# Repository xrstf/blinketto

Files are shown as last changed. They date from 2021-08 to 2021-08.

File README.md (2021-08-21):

# Blinketto - Controlling my PixelPals remotely

This repository contains the source code, schematics and everything else for my
LED controller.

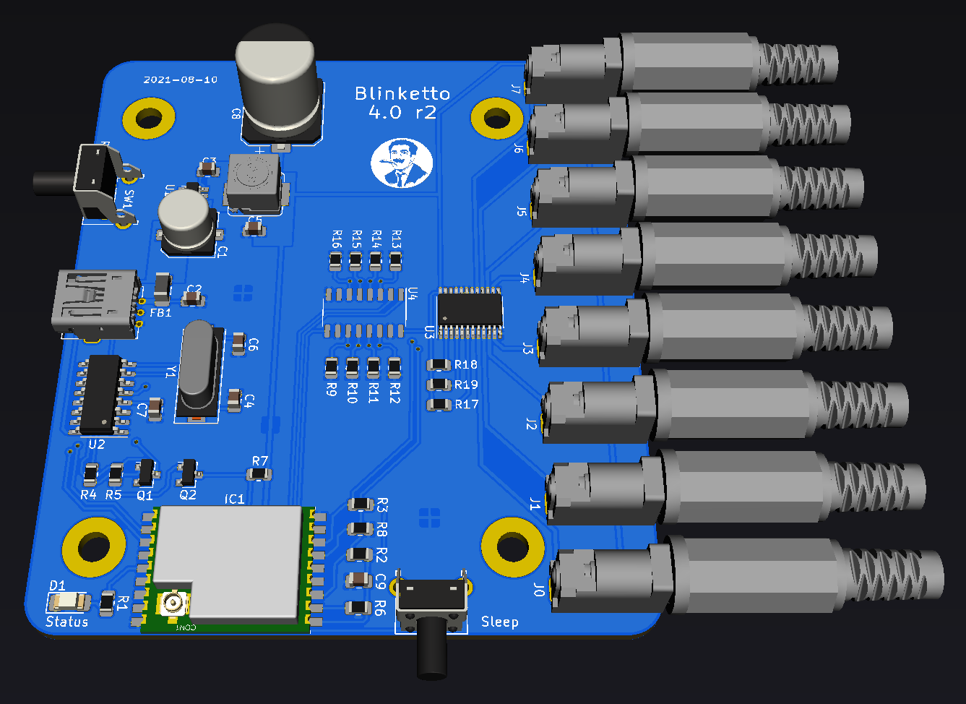
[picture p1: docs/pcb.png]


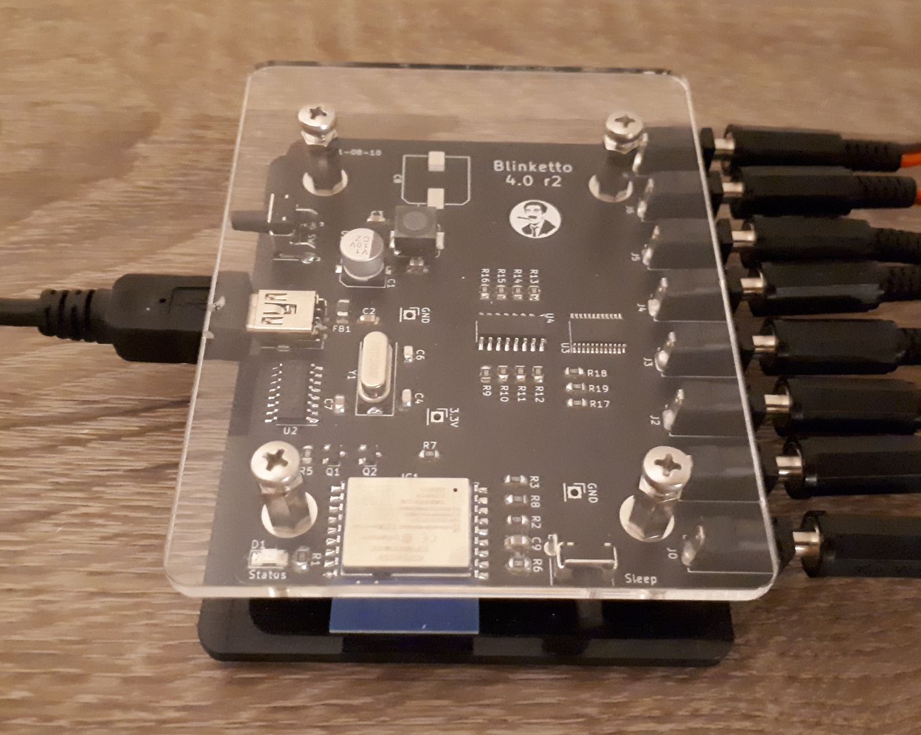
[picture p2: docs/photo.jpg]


---

Blinketto was named after the Plinketto device in one of my favorite web series,
["Best of the Worst"](https://www.youtube.com/user/RedLetterMedia).

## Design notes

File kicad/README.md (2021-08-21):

# KiCad Designs

These designs require that https://github.com/xrstf/kicad-library is set up in your
local KiCad 5 installation.

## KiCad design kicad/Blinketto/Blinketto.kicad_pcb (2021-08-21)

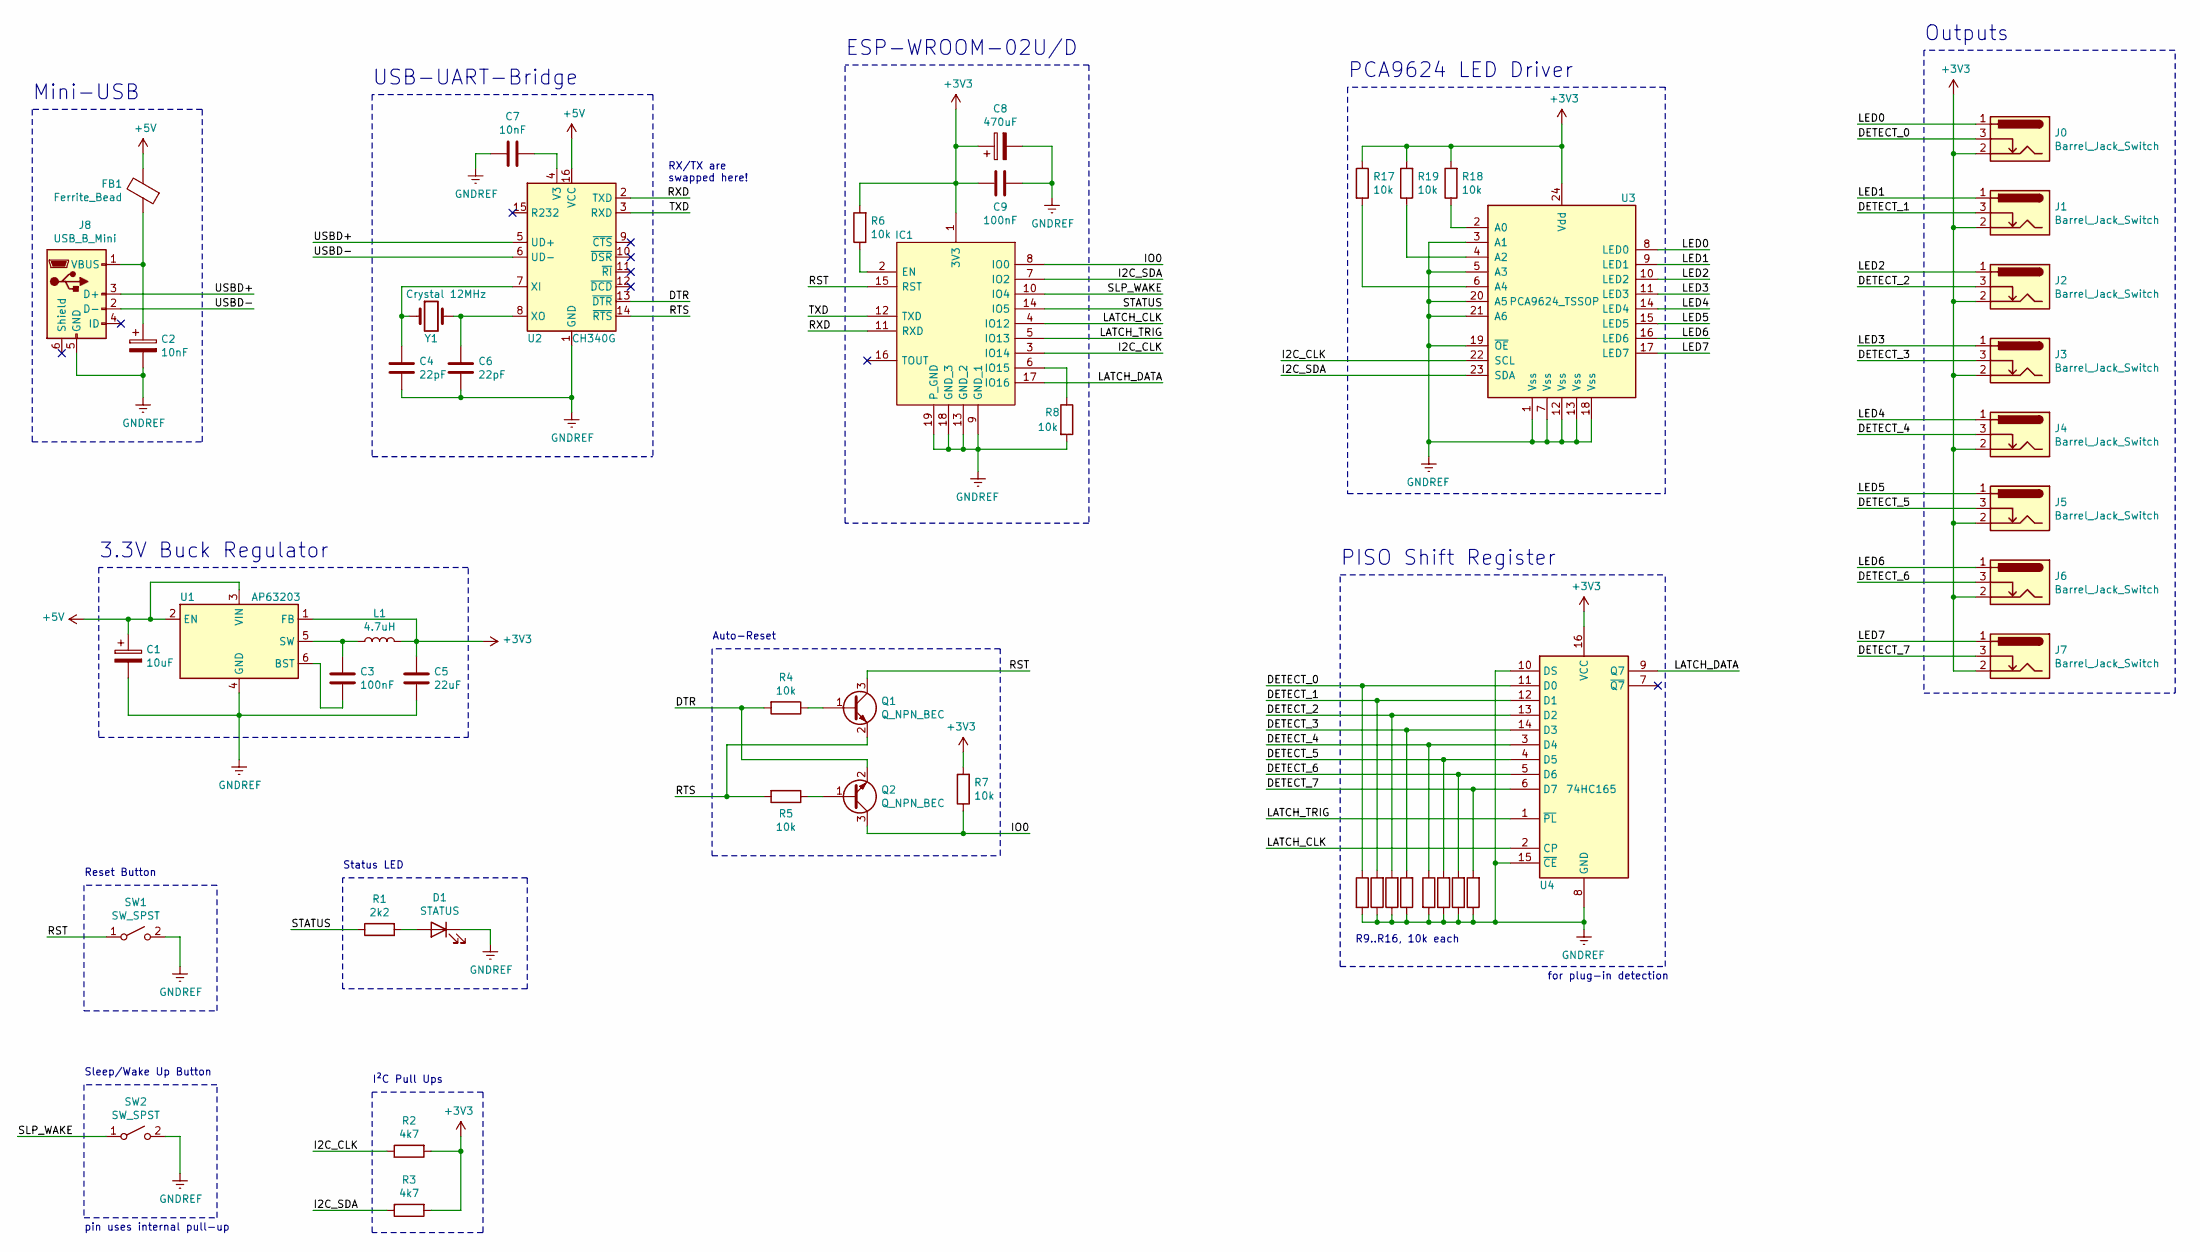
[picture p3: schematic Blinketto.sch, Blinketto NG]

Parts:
C1: 10uF; C_Elec_6.3x5.8
C2, C7: 10nF; C_0805_2012Metric
C3, C9: 100nF; C_0805_2012Metric
C4, C6: 22pF; C_0805_2012Metric
C5: 22uF; C_0805_2012Metric
C8: 470uF; CP_Elec_10x12.5
D1: STATUS; LED_1206_3216Metric_Pad1.42x1.75mm_HandSolder
FB1: Ferrite_Bead; L_1206_3216Metric_Pad1.42x1.75mm_HandSolder
IC1: ESP-WROOM-02U__4MB_; ESP-WROOM-02U
J0, J1, J2, J3, J4, J5, J6, J7: Barrel_Jack_Switch; Lumberg_1613-26_BarrelJack
J8: USB_B_Mini; USB_BWM_MIniUSB_THT_reichelt
L1: 4.7uH; Bourns_SRR0604_7.3x6.6mm
Q1, Q2: Q_NPN_BEC; SOT-23
R1: 2k2; R_0805_2012Metric
R2, R3: 4k7; R_0805_2012Metric
R4, R5, R6, R7, R8, R9, R10, R11, R12, R13, R14, R15, R16, R17, R18, R19: 10k; R_0805_2012Metric
SW1, SW2: SW_SPST; SW_Tactile_SPST_Angled_PTS645Vx83-2LFS
U1: AP63203; TSOT-23-6
U2: CH340G; SOIC-16_3.9x9.9mm_P1.27mm
U3: PCA9624_TSSOP; TSSOP-24_4.4x7.8mm_P0.65mm
U4: 74HC165; SO-16_3.9x9.9mm_P1.27mm
Y1: Crystal 12MHz; Crystal_SMD_HC49-SD

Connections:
+3V3: C5.2, C8.1, C9.1, IC1.1 (3V3), J0.2, J1.2, J2.2, J3.2, J4.2, J5.2, J6.2, J7.2, L1.2, R2.2, R3.2, R6.2, R7.2, R17.1, R18.2, R19.2, U1.1 (FB), U3.24 (Vdd), U4.16 (VCC)
+5V: C1.1, FB1.2, U1.2 (EN), U1.3 (VIN), U2.16 (VCC)
/DETECT_0: J0.3, R9.1, U4.11 (D0)
/DETECT_1: J1.3, R10.2, U4.12 (D1)
/DETECT_2: J2.3, R11.2, U4.13 (D2)
/DETECT_3: J3.3, R12.2, U4.14 (D3)
/DETECT_4: J4.3, R13.1, U4.3 (D4)
/DETECT_5: J5.3, R14.2, U4.4 (D5)
/DETECT_6: J6.3, R15.2, U4.5 (D6)
/DETECT_7: J7.3, R16.2, U4.6 (D7)
/DTR: Q2.2 (E), R4.2, U2.13 (~DTR)
/I2C_CLK: IC1.3 (IO14), R2.1, U3.22 (SCL)
/I2C_SDA: IC1.7 (IO2), R3.1, U3.23 (SDA)
/IO0: IC1.8 (IO0), Q2.3 (C), R7.1
/LATCH_CLK: IC1.4 (IO12), U4.2 (CP)
/LATCH_DATA: IC1.17 (IO16), U4.9 (Q7)
/LATCH_TRIG: IC1.5 (IO13), U4.1 (~PL)
/LED0: J0.1, U3.8 (LED0)
/LED1: J1.1, U3.9 (LED1)
/LED2: J2.1, U3.10 (LED2)
/LED3: J3.1, U3.11 (LED3)
/LED4: J4.1, U3.14 (LED4)
/LED5: J5.1, U3.15 (LED5)
/LED6: J6.1, U3.16 (LED6)
/LED7: J7.1, U3.17 (LED7)
/RST: IC1.15 (RST), Q1.3 (C), SW1.1 (A)
/RTS: Q1.2 (E), R5.2, U2.14 (~RTS)
/RXD: IC1.11 (RXD), U2.2 (TXD)
/SLP_WAKE: IC1.10 (IO4), SW2.1 (A)
/STATUS: IC1.14 (IO5), R1.1
/TXD: IC1.12 (TXD), U2.3 (RXD)
/USBD+: J8.3 (D+), U2.5 (UD+)
/USBD-: J8.2 (D-), U2.6 (UD-)
GNDREF: C1.2, C2.2, C4.1, C5.1, C6.1, C7.1, C8.2, C9.2, D1.1 (K), IC1.9 (GND_1), IC1.13 (GND_2), IC1.18 (GND_3), IC1.19 (P_GND), J8.5 (GND), R8.2, R9.2, R10.1, R11.1, R12.1, R13.2, R14.1, R15.1, R16.1, SW1.2 (B), SW2.2 (B), U1.4 (GND), U2.1 (GND), U3.1 (Vss), U3.3 (A1), U3.5 (A3), U3.7 (Vss), U3.12 (Vss), U3.13 (Vss), U3.18 (Vss), U3.19 (~OE), U3.20 (A5), U3.21 (A6), U4.8 (GND), U4.10 (DS), U4.15 (~CE)
unnamed: C2.1, FB1.1, J8.1 (VBUS)
unnamed: C3.1, U1.6 (BST)
unnamed: C3.2, L1.1, U1.5 (SW)
unnamed: C4.2, U2.7 (XI), Y1.1
unnamed: C6.2, U2.8 (XO), Y1.2
unnamed: C7.2, U2.4 (V3)
unnamed: D1.2 (A), R1.2
unnamed: IC1.2 (EN), R6.1
unnamed: IC1.6 (IO15), R8.1
unnamed: Q1.1 (B), R4.1
unnamed: Q2.1 (B), R5.1
unnamed: R17.2, U3.6 (A4)
unnamed: R18.1, U3.2 (A0)
unnamed: R19.1, U3.4 (A2)

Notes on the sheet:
Mini-USB
Status LED
Auto-Reset
ESP-WROOM-02U/D
Reset Button
3.3V Buck Regulator
PCA9624 LED Driver
PISO Shift Register
for plug-in detection
Outputs
Sleep/Wake Up Button
I²C Pull Ups
RX/TX are swapped here!
USB-UART-Bridge
pin uses internal pull-up
R9..R16, 10k each

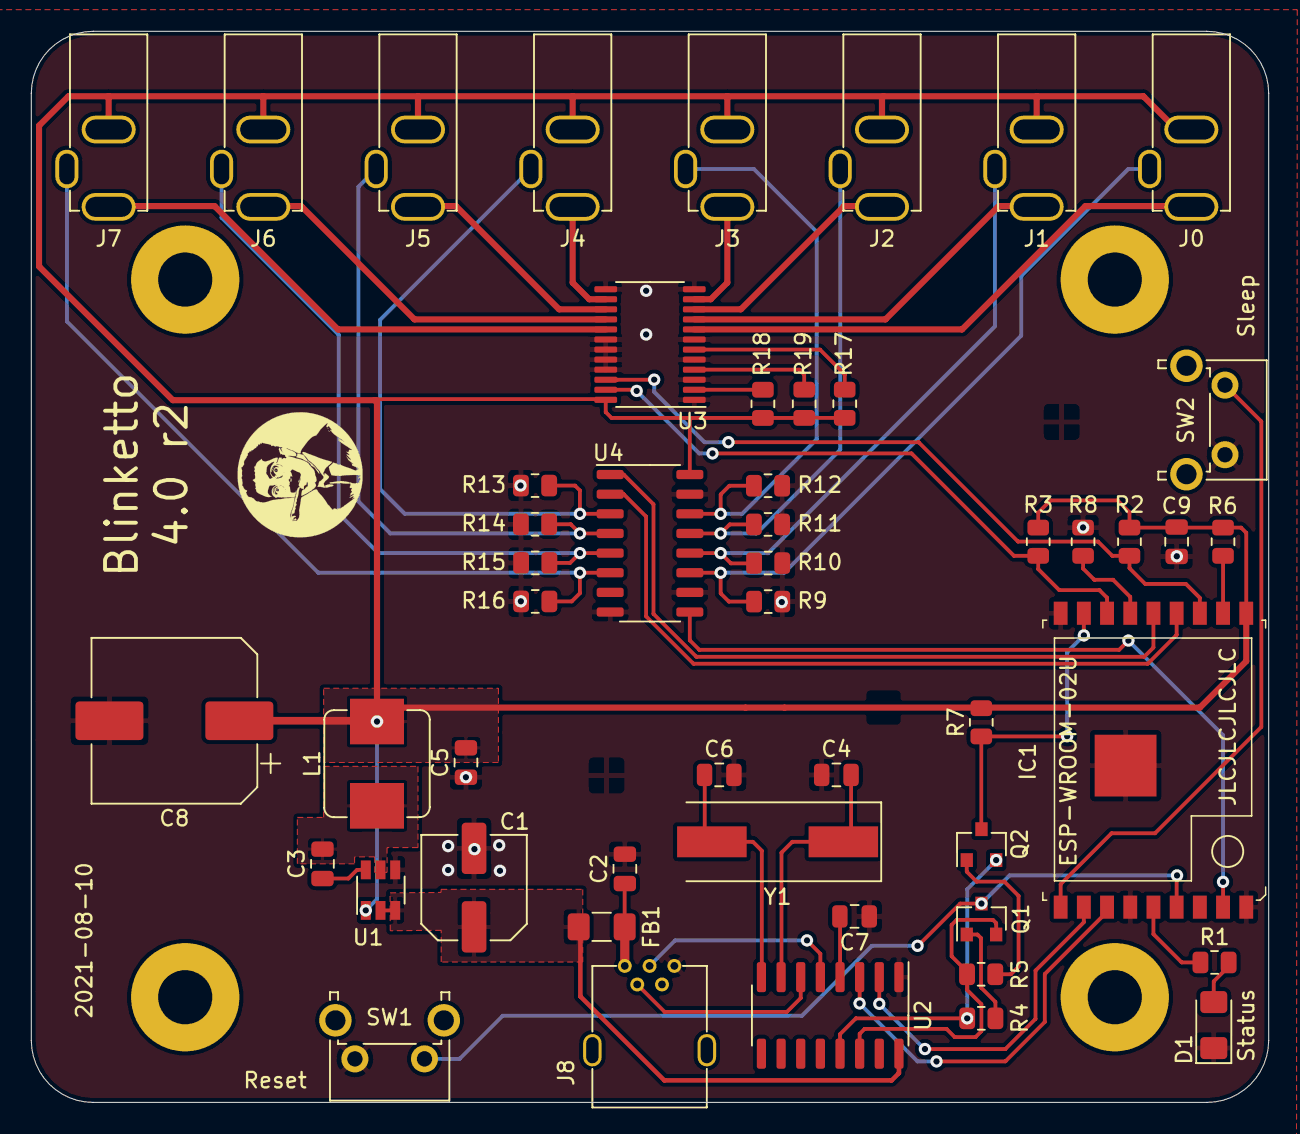
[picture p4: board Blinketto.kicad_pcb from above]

Board: 2 copper layers, 80.0 x 69.2 mm, 50 parts (0 on the bottom side), 48 nets.

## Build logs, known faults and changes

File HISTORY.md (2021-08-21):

# Blinketto History

Come on, sit down and let's have a laugh at the things I fucked up and what I learned over time. :)

## Blinketto 1.x

Was still based on a PIC microcontroller and I never designed a board for this. Getting
starting with PICs was more effort than expected, so I reverted back to Atmel and Arduino IDE
for 2.x

## Blinketto 2.0

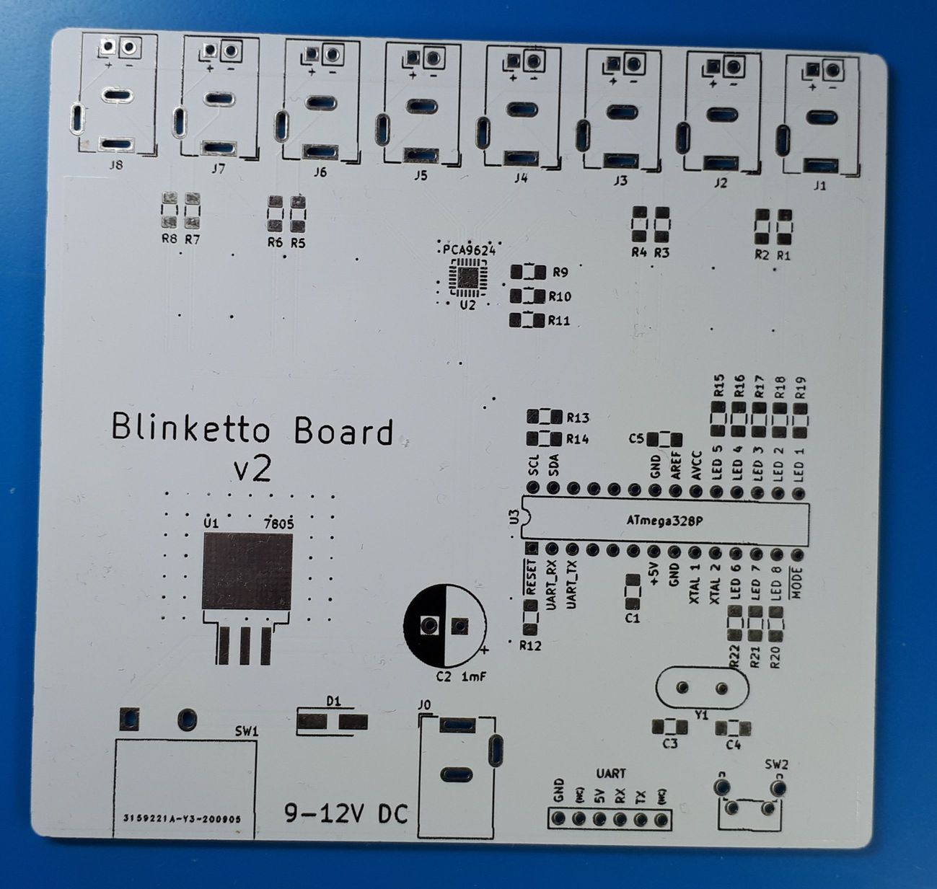
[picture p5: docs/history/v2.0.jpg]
Blinketto 2.0


The first version.

Things that sucked:

* The footprint for the LED driver was too hard for me to solder by hand. I ruined 2 boards while
  attempting to solder. At that point I did not own a hot air station or a heat plate.
* Debugging the I²C bus between the ATmega and the LED driver was impossible.
* No status LEDs, so I often wasn't even sure if the microcontroller was doing anything.
* White PCBs are amazingly ugly.

## Blinketto 2.1

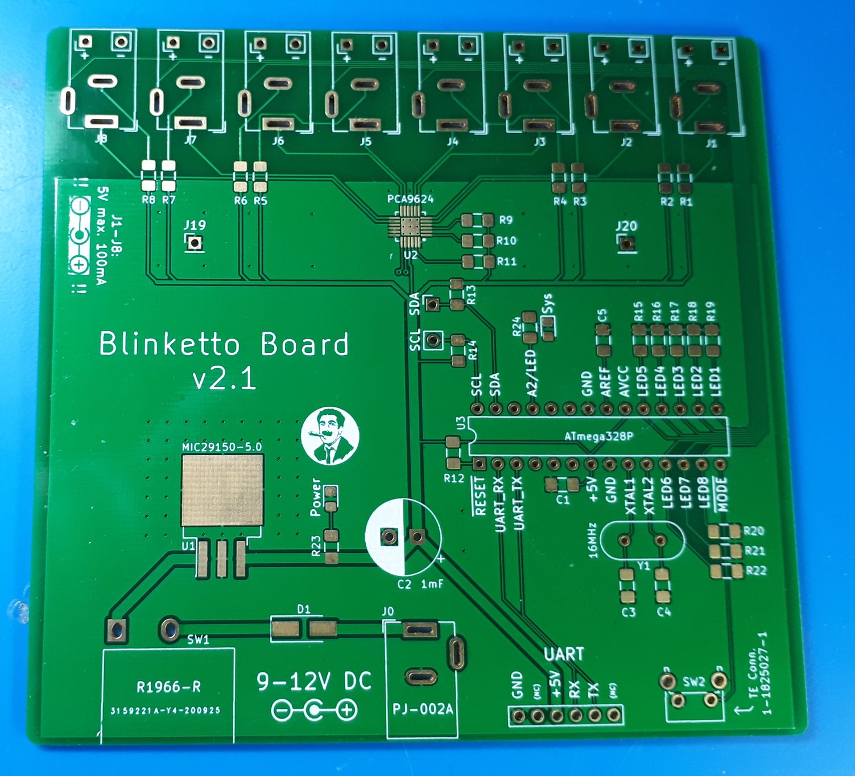
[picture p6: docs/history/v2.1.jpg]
Blinketto 2.1


Now with fancy status LEDs, pin headers to allow debugging the I²C bus and a modified footprint
for the LED driver, making soldering easier. J19 and J20 provide easier access to GND. I also put
better silkscreen on it, describing the pinouts and parts in more detail.

## Blinketto 2.2

The LED driver footprint was still too hard to solder, but I learned that a TSSOP package was
also available, so I switched over. Unfortunately I did not expect that the pinout would change
(i.e. pin 6 on the TSSOP is different from pin 6 on the LGA package), so my board was fubar.
I caught this before ordering and fixed it in v2.3.

## Blinketto 2.3

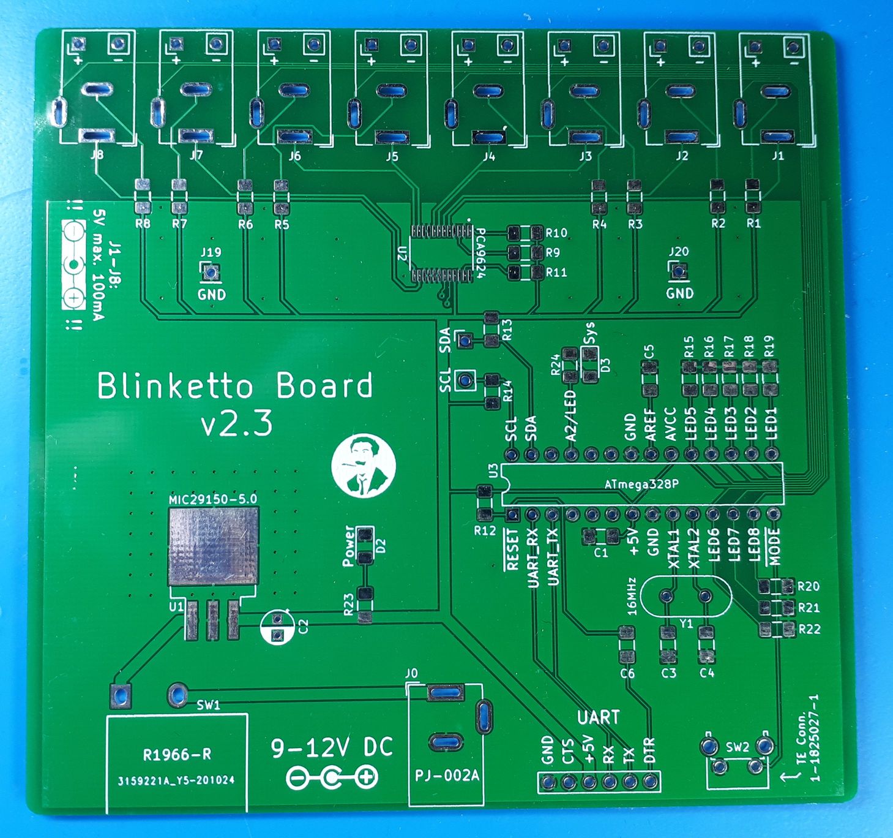
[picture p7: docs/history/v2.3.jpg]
Blinketto 2.3


This is the first time I realized that the 2 pins I didn't connect before (CTS and DTR)
are actually useful and required to make the UART stuff and uploading via Arduino IDE possible.
So I begun connecting them properly.

## Blinketto 3.0

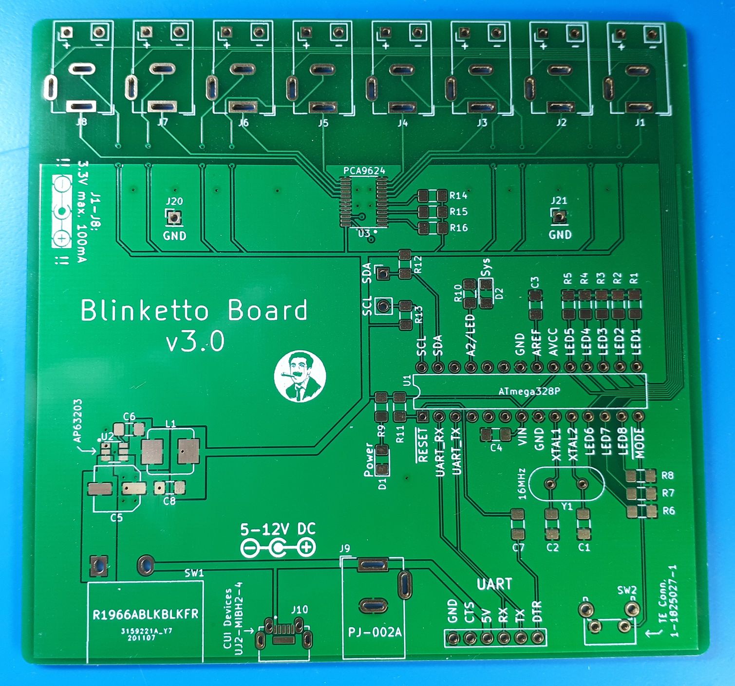
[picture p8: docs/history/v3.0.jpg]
Blinketto 3.0


The linear regulator was easy to use, but ran very hot (expectedly). I felt brave enough to
layout a buck regulator instead for v3.0, increasing efficiency greatly. As I now regulate down
to 3V, using USB to power Blinketto was now also possible, even though I think I routed it wrongly,
as it never worked for me.

The PCA LED driver is also much better routed in this version.

## Blinketto 4 r1

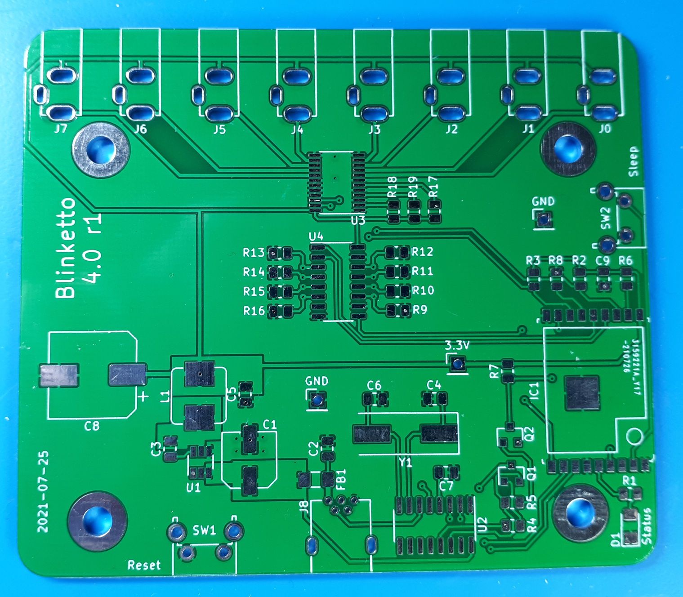
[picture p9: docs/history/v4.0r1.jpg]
Blinketto 4.0r1


While Blinketto 3 was "in production" for a good year, I ordered a bunch of plexiglas panes for my
projects. These were meant to be used for all sorts of my projects, like [Frøy](https://github.com/xrstf/froy),
so I wanted to refresh Blinketto with the stuff I learned over the year.

It now has a USB->UART converter on board, which makes programming it much easier. The ESP8266
instead of ATmega adds nice WiFi capabilities, but required an additional shift register as an I/O
expander, as the ESP-WROOM-02 does not have enough pins for all 8 LED devices.

## Blinketto 4 r2

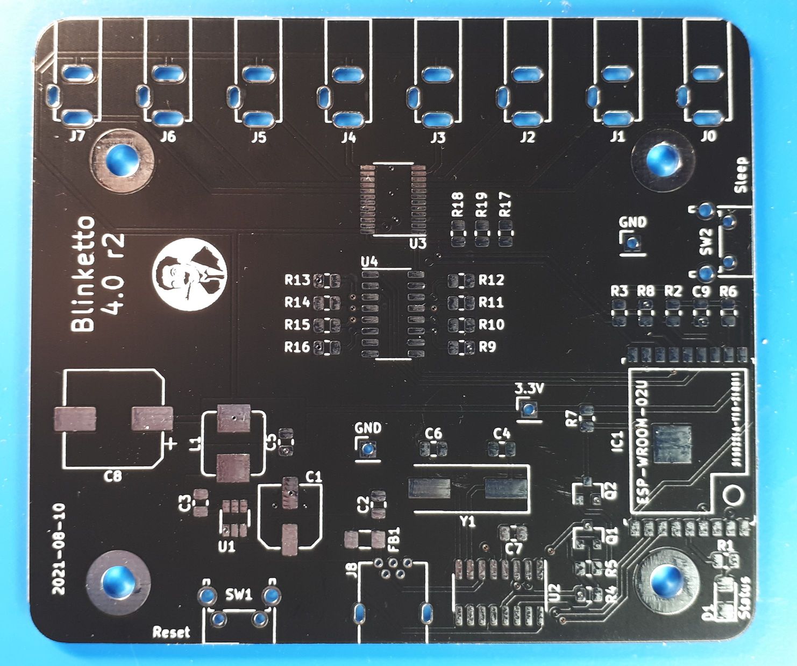
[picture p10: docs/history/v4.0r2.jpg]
Blinketto 4.0r2


There was a single mistake in revision 1: The pin I chose for the sleep button was GPIO16.
Unfortunately this is the only GPIO pin that does not support interrupts, which were critical to
make the button work reliably. So I had to just switch the button to a different pin.

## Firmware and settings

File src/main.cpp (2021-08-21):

/*
 To flash this, choose the following settings in the Arduino IDE:

     - board:        Generic ESP8266 Board
     - upload speed: 115200
     - reset mode:   "dtr (aka nodemcu)" for mini-reset-circuit
                                     "no dtr (aka ck)" for kevin's circuit

 To ensure EEPROM works:

     - flash frequency: 26Mhz
     - flash size:      2MB (FS: 64KB)

 The remaining things can be left as-is.
*/

#include "cli.h"
#include "config.h"
#include "driver.h"
#include "eeprom.h"
#include "global.h"
#include "interrupter.h"
#include "plugman.h"
#include "webserver.h"
#include "wifi.h"
#include <blinketto.h>
#include <blinketto_mode_blink.h>
#include <blinketto_mode_counter.h>
#include <blinketto_mode_kitt.h>
#include <blinketto_mode_on.h>
#include <blinketto_mode_random_fade.h>
#include <xrstf_arduino_util.h>
#include <xrstf_util.h>

PlugManager plugMan(SHIFTREGISTER_CLK_PIN, SHIFTREGISTER_LOAD_PIN, SHIFTREGISTER_DATA_PIN);
PCA9624Driver *driver;
Blinketto *blinketto;
Interrupter *interrupter;

bool runModeOn() {
	BlinkettoModeOn mode;
	if (!mode.canRun(*blinketto)) {
		return false;
	}

	mode.run(*blinketto, *interrupter);
	return true;
}

bool runModeBlink() {
	BlinkettoModeBlink mode(&global::config.modeBlinkConfig);
	if (!mode.canRun(*blinketto)) {
		return false;
	}

	mode.run(*blinketto, *interrupter);
	return true;
}

bool runModeCounter() {
	BlinkettoModeCounter mode(&global::config.modeCounterConfig);
	if (!mode.canRun(*blinketto)) {
		return false;
	}

	mode.run(*blinketto, *interrupter);
	return true;
}

bool runModeRandomFade() {
	BlinkettoModeRandomFade mode(&global::config.modeRandomFadeConfig);
	if (!mode.canRun(*blinketto)) {
		return false;
	}

	mode.run(*blinketto, *interrupter);
	return true;
}

bool runModeKitt() {
	BlinkettoModeKitt mode(&global::config.modeKittConfig);
	if (!mode.canRun(*blinketto)) {
		return false;
	}

	mode.run(*blinketto, *interrupter);
	return true;
}

// without IRAM_ATTR, the ESP crashes when calling attachInterrupt,
// see https://github.com/esp8266/Arduino/issues/6237
void IRAM_ATTR onSleepButtonPress() {
	global::sleepButtonPressed = millis();
}

void setup() {
	xrstf::setupLED(LED_PIN);
	cli::setup();
	eeprom::init();
	eeprom::load(&global::config);
	wifi::connect();
	webserver::setup();
	webserver::start(&global::config);

	pinMode(SLEEP_BUTTON_PIN, INPUT_PULLUP);
	attachInterrupt(digitalPinToInterrupt(SLEEP_BUTTON_PIN), onSleepButtonPress, FALLING);

	Wire.begin(I2C_SDA_PIN, I2C_SCK_PIN);

	driver = new PCA9624Driver(I2C_ADDRESS);
	driver->setLEDStates(plugMan.getStatus());

	xrstf::blinkLED(LED_PIN, 3);

	delay(1000);

	blinketto   = new Blinketto(*driver, 0xFF);
	interrupter = new Interrupter(&global::config, plugMan, *driver);

	// set the actual full brightness
	// (Blinketto constructor requires 0..0xFF, but EEPROM stores a percentage)
	blinketto->setFullBrightness(global::config.brightness);
}

void loop() {
	// Loop until we have at least a single output plugged in
	if (blinketto->numActiveLEDs() == 0) {
		interrupter->shouldInterrupt(*blinketto);
		delay(250);
		return;
	}

	// if a runMode* function returns false, that means that
	// the mode is not possible to be used (e.g. because of too
	// few outputs); in those cases we simply skip over to the
	// next mode.

	switch (global::config.mode) {
	case MODE_BLINK:
		if (runModeBlink()) {
			break;
		}
		// fallthroughh

	case MODE_COUNTER:
		if (runModeCounter()) {
			break;
		}
		// fallthroughh

	case MODE_RANDOM_FADE:
		if (runModeRandomFade()) {
			break;
		}
		// fallthroughh

	case MODE_KITT:
		if (runModeKitt()) {
			break;
		}
		// fallthroughh

	case MODE_FULL_ON:
		if (runModeOn()) {
			break;
		}
		// fallthroughh

	case MODE_NONE:
		delay(250);
		break;
	}
}

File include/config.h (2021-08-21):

#pragma once

#include <stdint.h>

// informational purpose only
#define BLINKETTO_VERSION "3.0"

// set to 0 if there is no status LED on the board
#define LED_PIN 5

// GPIO pin for the sleep mode button
#define SLEEP_BUTTON_PIN 4

// pins for the PISO shift register
#define SHIFTREGISTER_LOAD_PIN 13
#define SHIFTREGISTER_DATA_PIN 16
#define SHIFTREGISTER_CLK_PIN  12
// #define SHIFTREGISTER_CLKINH_PIN 6 // always low in board 4.0 rev1

// Only some of the variants maintained in https://github.com/esp8266/Arduino/tree/master/variants
// have the correct pinout for an ESP-WROOM-02. To keep the code generic,
// we define our own constants. In the Arduino IDE, just choose "ESP8266 Generic".
#define I2C_SDA_PIN 2  // this is GPIO2, on physical pin 7
#define I2C_SCK_PIN 14 // this is GPIO14, on physical pin 3
#define I2C_ADDRESS 0x15

#define MODE_NONE        0
#define MODE_FULL_ON     1
#define MODE_BLINK       2
#define MODE_COUNTER     3
#define MODE_RANDOM_FADE 4
#define MODE_KITT        5

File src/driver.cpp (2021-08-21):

#include "driver.h"
#include "util.h"
#include <blinketto.h>
#include <cstring>
#include <xrstf_util.h>

PCA9624Driver::PCA9624Driver(uint8_t i2cAddress)
	: driver(i2cAddress), mode(BLINKETTO_NO_MODE), ledStates{0}, brightnesses{0} {
	char autoinc = PCA9624_AI_OFF;
	char sleep   = 0; // the only flag we actually want to change
	char sub1    = 0;
	char sub2    = 0;
	char sub3    = 0;
	char allcall = 0;
	char addr    = PCA9624_ADDR_CHIP;

	this->driver.writeMode1(autoinc, sleep, sub1, sub2, sub3, allcall, addr);

	// the PCA remembers the individual brightness levels
	// when our MCU reboots, so make sure to clean that up
	this->setAll(BLKO_BRIGHTNESS_OFF);
}

void PCA9624Driver::setAll(uint8_t brightness) {
	uint8_t brightnesses[BLKO_MAX_OUTPUTS];
	memset(brightnesses, brightness, BLKO_MAX_OUTPUTS);
	this->setBrightnesses(brightnesses);
}

void PCA9624Driver::turnOff() {
	this->setMode(BLKO_MODE_OFF);
}

void PCA9624Driver::turnOn(uint8_t brightness) {
	this->setAll(brightness);
}

bool PCA9624Driver::setBrightness(uint8_t led, uint8_t brightness) {
	if (led >= BLKO_MAX_OUTPUTS) {
		return false;
	}

	this->setMode(BLKO_MODE_INDIVIDUAL);
	this->driver.writePWM(led, brightness, PCA9624_ADDR_CHIP);
	this->brightnesses[led] = brightness;

	return true;
}

void PCA9624Driver::setBrightnesses(uint8_t brightnesses[BLKO_MAX_OUTPUTS]) {
	this->setMode(BLKO_MODE_INDIVIDUAL);
	this->driver.writeAllPWMs((char *)brightnesses, 0, 0);
	memcpy(this->brightnesses, brightnesses, sizeof(uint8_t) * BLKO_MAX_OUTPUTS);
}

void PCA9624Driver::setLEDStates(uint8_t newState) {
	this->ledStates = newState;
	this->turnOff();
}

uint8_t PCA9624Driver::getLEDStates() {
	return this->ledStates;
}

void PCA9624Driver::getBrightnesses(uint8_t brightnesses[BLKO_MAX_OUTPUTS]) {
	for (uint8_t i = 0; i < BLKO_MAX_OUTPUTS; ++i) {
		brightnesses[i] = this->brightnesses[i];
	}
}

void PCA9624Driver::setMode(uint8_t mode) {
	if (mode != this->mode) {
		uint8_t pcaMode = PCA9624_LED_OFF;

		switch (mode) {
		case BLKO_MODE_OFF:
			pcaMode = PCA9624_LED_OFF;
			break;

		case BLKO_MODE_ON:
			pcaMode = PCA9624_LED_ON_NO_CONTROL;
			break;

		case BLKO_MODE_INDIVIDUAL:
			pcaMode = PCA9624_LED_INDIVIDUAL;
			break;
		}

		this->writeLedOutputState(pcaMode);
		mode = this->mode;
	}
}

void PCA9624Driver::writeLedOutputState(uint8_t active, uint8_t inactive) {
	this->driver.writeLedOut(CHECK_BIT(this->ledStates, 0) ? active : inactive, CHECK_BIT(this->ledStates, 1) ? active : inactive, CHECK_BIT(this->ledStates, 2) ? active : inactive, CHECK_BIT(this->ledStates, 3) ? active : inactive,
																																																			CHECK_BIT(this->ledStates, 4) ? active
																																																										  : inactive,
																																																			CHECK_BIT(this
																																																																																																																																																							->ledStates,
																																																																																																					5)
																																																																																																					? active
																																																																																																					: inactive,
																																																			CHECK_BIT(this->ledStates, 6)
																																																																																																					? active
																																																																																																					: inactive,
																																																			CHECK_BIT(this->ledStates, 7) ? active
																																																										  : inactive);
}
